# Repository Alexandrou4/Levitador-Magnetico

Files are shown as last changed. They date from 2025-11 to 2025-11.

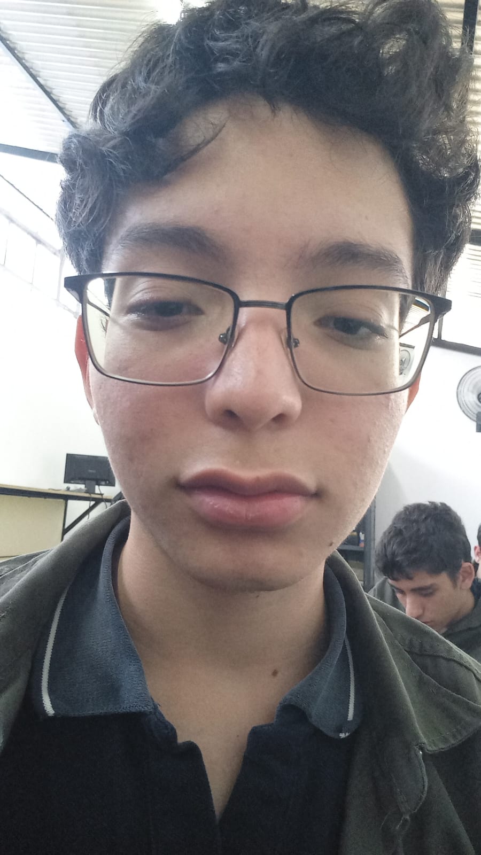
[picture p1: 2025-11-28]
app/Sitio Web/Imagenes/ALEEEEE.jpg

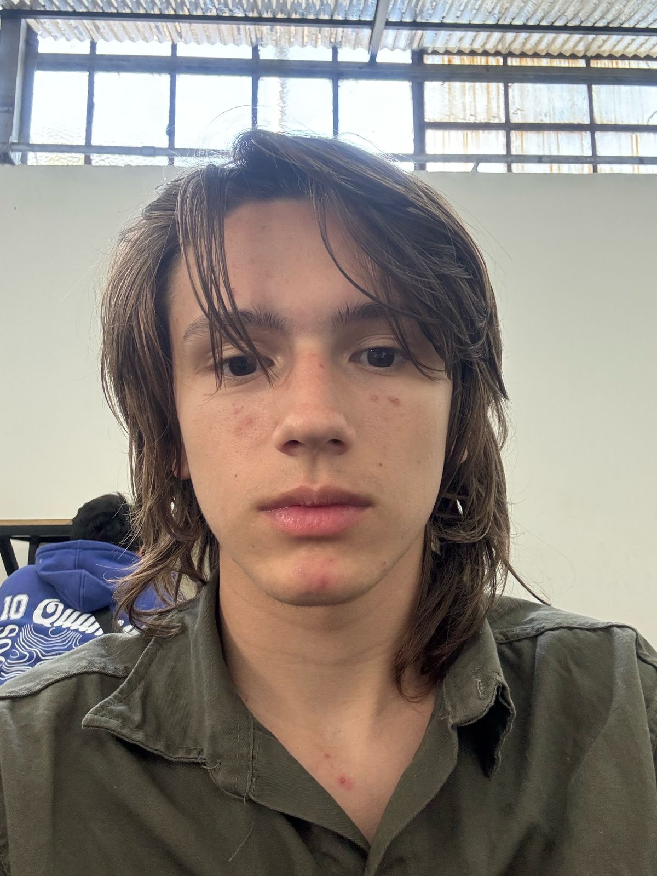
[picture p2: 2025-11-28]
app/Sitio Web/Imagenes/ren.jpg

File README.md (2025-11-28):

<h1 align="center"> **LEVITADOR MAGNÉTICO** </h1>

<h2> Nuestro proyecto, un levitador magnético por repulsión es un dispositivo que utiliza la fuerza de campos magnéticos para suspender un objeto en el aire sin contacto físico. </h2>

<h2> En este utilizamos los principios de electromagnetismo y corrientes eléctricas, PWM (Pulse Width Modulation/Modulación por Ancho de Pulso) y PID (Proporcional-Integral-Derivativo) como un sistema de control para regular constantemente la tensión media inducida en un electroimán en tiempo real y un circuito de potencia que nos permite tener la suficiente alimentación para el bobinado. </h2>

<h2> En este repositorio de Github se encuentran varios directorios como documentación, archivos del firmware, hardware y del sitio web para el facil acceso del lector, con una breve exlicación de los contenidos de cada dirección </h2>

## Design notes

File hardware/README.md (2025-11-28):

<h1 align="center"> HARDWARE </h1>

<h2> Se encuentra una gran parte de los archivos del proyecto en este directorio</h2>

<h2> Se incluyen:</h2>

<h3> -Esquemático</h3>
<h3> -PCB</h3>
<h3> -Gerber</h3>
<h3> -Simbolo RP2040-Zero</h3>
<h3> -Footprint RP2040-Zero</h3>

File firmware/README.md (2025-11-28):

<h1 align="center"> CÓDIGO </h1>

<h2> Código del proyecto insertado en una RP2040-Zero</h2>

<h2> En este código se incluyen los modulos PWM y PID, entra la lectura del SS49E, pasa por una serie de calculos con la funcion PID, y la salida de estos calculos es establecido como el wrap del PWM0 que sale hacia el driver de potencia.</h2>

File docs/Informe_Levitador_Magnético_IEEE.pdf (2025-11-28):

# Informe IEEE Levitador Magnetico ´

1

ro Villegas Gonzalez Alejandro ´
6° 2° AVC
Comision C ´
alejandrovillegasgonzalez@impatrq.com

4

to Gonzalez Camiscia Santiago
6° 2° AVC
Comision C ´
santiagogonzalezcamiscia@impatrq.com

2

do Romero Julian
6° 2° AVC
Comision B ´
julianromero@impatrq.com

5

to Keller Mateo
6° 2° AVC
Comision C ´
mateokeller@impatrq.com

3

ro Erbino Renzo
6° 2° AVC
Comision C ´
renzoerbino@impatrq.com

6

to Gonzalez Paurailly Matias
6° 2° AVC
Comision C ´
matiasgonzalezpaurailly@impatrq.com

Abstract—En este informe se detalla el desarrollo tecnico ´ llevado a cabo, se analiza la metodolog´ıa y conceptos f´ısicos utilizados en el proyecto tales como el PWM y PID, la manera en la que conseguimos la posicion del objeto que levita y como ´
la controlamos mediante el codigo y se demuestra gr ´ | aficamente ´
los procesos que suceden en el circuito tanto electrica como digitalmente.
I. INTRODUCCION´
En este informe estaremos detallando el funcionamiento y desarrollo de nuestro proyecto, un levitador magnetico por ´ repulsion. Este es un dispositivo que utiliza la fuerza de ´ campos magneticos para suspender un objeto en el aire sin ´ contacto f´ısico. En este utilizamos los principios de electromagnetismo y corrientes electricas, PWM (Pulse Width Modu- ´ lation/Modulacion por Ancho de Pulso) y PID (Proporcional- ´ Integral-Derivativo) como un sistema de control para regu-lar constantemente la tension media inducida en un elec- ´ troiman en tiempo real y un circuito de potencia que nos ´ permite tener la suficiente alimentacion para el bobinado. ´
Demostraremos como se realizo y acab ´ | o el proyecto a trav ´ | es´
de los conocimientos que obtuvimos en el proceso y los problemas que tuvimos que superar, los componentes y su
descripcion, la configuracion de estos y el c ´ | odigo que uti- ´
lizamos para lograr que cada etapa del circuito funcione adecuadamente. En la seccion de referencias del documento ´ se incluira un enlace al repositorio de Github del proyecto, ´
donde encontraran informaci ´ | on m ´ | as especifica sobre algunas ´
de las distintas categorias del contenido de este informe.

II. DESCRIPCION´ FUNCIONAL

A. Diagrama en bloques

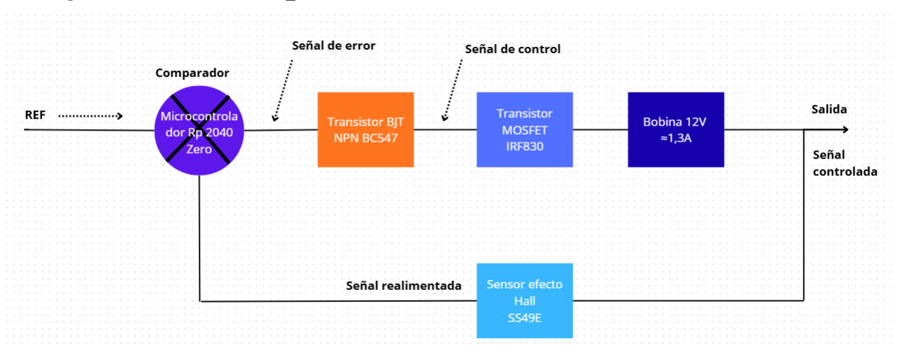
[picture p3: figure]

Fig. 1: Diagrama en bloques del circuito

B. Diagrama de codigo ´

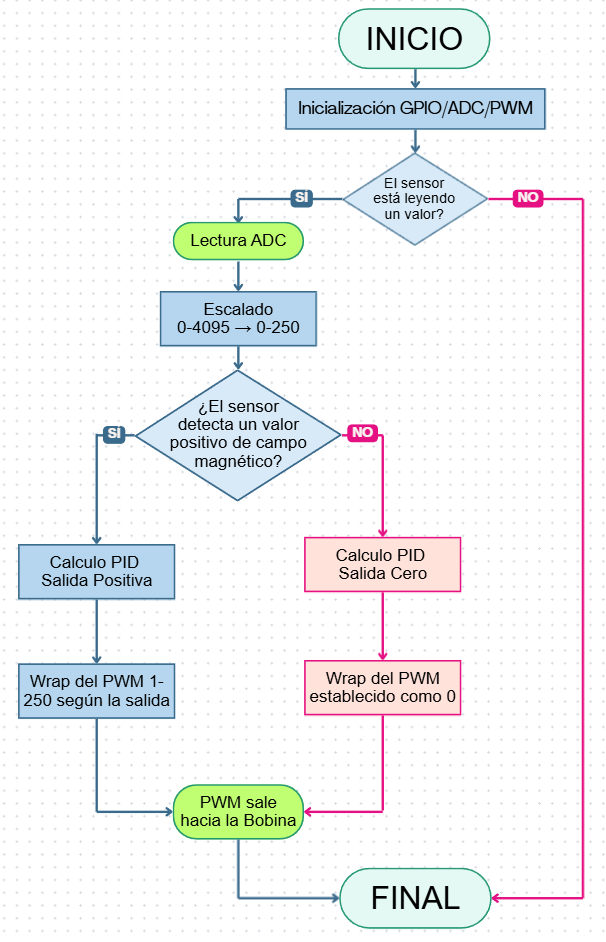
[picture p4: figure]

Fig. 2: Diagrama de codigo del circuito ´

C. Descripcion de circuitos ´
- Microcontrolador RP2040 Zero: Este Microcontrolador es el principal encargado de recibir y procesar los datos provenientes del sensor de efecto Hall. El valor sensado entra a ADC1, donde la computadora lee un valor de 0-4095 y pasa por una serie de calculos con un sistema ´ de control PID con el objetivo de darnos un resultado en permanente oscilacion cercano a un setpoint indicado ´ (126). Este resultado esta escalado en valores de 0-250 y ´ se establece como el wrap de la salida PWM0.
- Diodo HFA15TB60: Evita el dano inmenso que puede ˜ ser generado al MOSFET a causa del alto pico de tension inversa que se genera cuando se apaga la bobina, ´ proporcionando un camino mas seguro para que se disipe ´ esa gran cantidad de energ´ıa.
- Transistor BJT (Driver Inversor): Invierte la senal PWM0 ˜ del microcontrolador, activandose cuando le entra una senal desde PWM0 y apagando el MOSFET, y permi- ˜ tiendo la entrada de la tension de VCC al Gate del ´ MOSFET cuando este no recibe ninguna senal, de tal ˜ modo que a´ısla al microcontrolador de la potencia.
- Transistor MOSFET: Este MOSFET de potencia es el componente que soporta el alto voltaje (VCC) del circuito
y actua como un interruptor electr ´ | onico para la bobina. ´
La senal PWM0 lo controla, y cuando este se prende y se ˜ apaga hace lo mismo con la bobina, conectando su paso a GND.
- Sensor de efecto Hall: Se encarga de sensar el campo electromagnetico generado por la bobina y proporciona ´
un valor de tension anal ´ | ogico que var ´ | ´ıa entre 0V-3.3V
que es le´ıdo por el ADC1 del microcontrolador. Cuando
este no recibe ningun campo magn ´ | etico otorga un valor ´
equivalente a la mitad de la tension de alimentaci ´ | on, en ´
este caso, 1.67V.
- Bobinado: Genera un campo magnetico variable seg ´ | un´
la tension que se le otorga por PWM0 que es le ´ | | ´ıdo por
el sensor de efecto Hall y a su vez permite la repulsion´ con el objeto acoplado a los imanes de neodimio.

III. ALCANCE LOGRADO

Durante el transcurso de este proyecto hemos logrado armar
un electroiman capaz de generar un campo electromagn ´ | etico ´
lo suficientemente potente como para poder repeler una pieza
unida a un iman de neodimio; programar un c ´ | odigo [ ´ | 3] capaz
de generar una salida de PWM(Pulse Width Modulation),
basandose en una se ´ | nal de referencia (Setpoint) y una se ˜ | nal ˜
sensada por el sensor de efecto hall siguiendo un sistema de control PID(Proporcional-Integral-Derivativo); disenar ˜ un circuito capaz de controlar la potencia de la bobina a
traves de la tensi ´ | on media generada por el c ´ | odigo (PWM0), ´
y posteriormente, utilizando la CNC pasarlo a una placa de cobre, perforarla y soldar los componentes; crear una base de madera [4] que pueda sostener de manera vertical a la
bobina y al sensor, contando tambien con un tubo de pl ´ | astico ´
transparente fijado a la parte superior del electroiman el cual ´ impide que la pieza [5] se intente dar vuelta; realizar pruebas, no solo del funcionamiento de la etapa de potencia y del
codigo sino tambi ´ | en de todo al mismo tiempo, verificando si ´
la tension media de la bobina es la indicada por el c ´ | odigo y ´
poder solucionar los problemas que nos encontramos en estas pruebas.

El alcance logrado ha llegado a ser el que nos propusimos como objetivo final tras varios replanteamientos, con lo que logramos el funcionamiento de un levitador electromagnetico ´ pero no sin reducir la propuesta de tres modulos de dos ´ etapas de potencia, un bobinado y un sensor cada uno, con la capacidad de lograr que el objeto levitado permanezca totalmente estatico en el aire. Por otro lado, pudimos realizar ´ una placa f´ısica [6] con el circuito, pero al no suceder lo que deb´ıa esta fue descartada e hicimos nuevamente una
simulacion en un protoboard [ ´ | 7] con otro esquematico [ ´ | 8] y
PCB [9], cuyo funcionamiento cumpl´ıa con el establecido originalmente.

IV. CONCLUSIONES

Con la finalizacion de este proyecto, alcanzamos a aprender ´ la integracion eficaz de los sistemas de control PWM y PID, ´ tambien siendo utilizados los principios de electromagnetismo, ´
calculos matem ´ | aticos complejos tales como las integrales y ´
derivadas que fueron clave para la realizacion del c ´ | odigo e ´
investigamos sobre las propiedades de los cables de cobre, calculo de impedancia por numero de vueltas en una bobina ´
y la maxima corriente capaz de pasar a trav ´ | | es de esta. ´

Logramos entender que el proyecto podr´ıa haber funcionado sin tener que encontrarnos con la gran cantidad de problemas que surgieron a medida que trabajabamos con el proyecto, ´ pero la inmensa obtencion de aprendizaje por la que pasamos ´ no hubiera sido posible sin estos, provocando as´ı que la solucion de los mismos ayude a encaminarnos hacia el ´ correcto funcionamiento del proyecto. A esto se le agrega que el tiempo que dedicamos para el desarrollo del proyecto fue limitado, causando que no hayamos podido realizar la vision´ original que ten´ıamos para este, si no una que se nos ocurrio´ en busqueda de solucionar los errores. Las principales ideas ´ que nos vimos obligados a descartar por la falta de tiempo
fueron la de una pagina web [ ´ | 10] en la que uno controlaba el
angulo de un avi ´ | on, y esto se ve ´ | ´ıa reflejado en la distancia a
la que el objeto a levitar lo hac´ıa, y que hubieran 3 modulos ´ con la configuracion actual, en vez de solo uno, con esto nos ´ referimos a 3 bobinas, sensores y una etapa de potencia en cada una.

En esta etapa final del proyecto concluimos que a pesar de los problemas atravesados el proyecto cumple con su objetivo original integrando los conocimientos de varias areas de taller y aula, dejando en claro las bases sentadas ´ para la mejora y optimizacion del mismo. ´

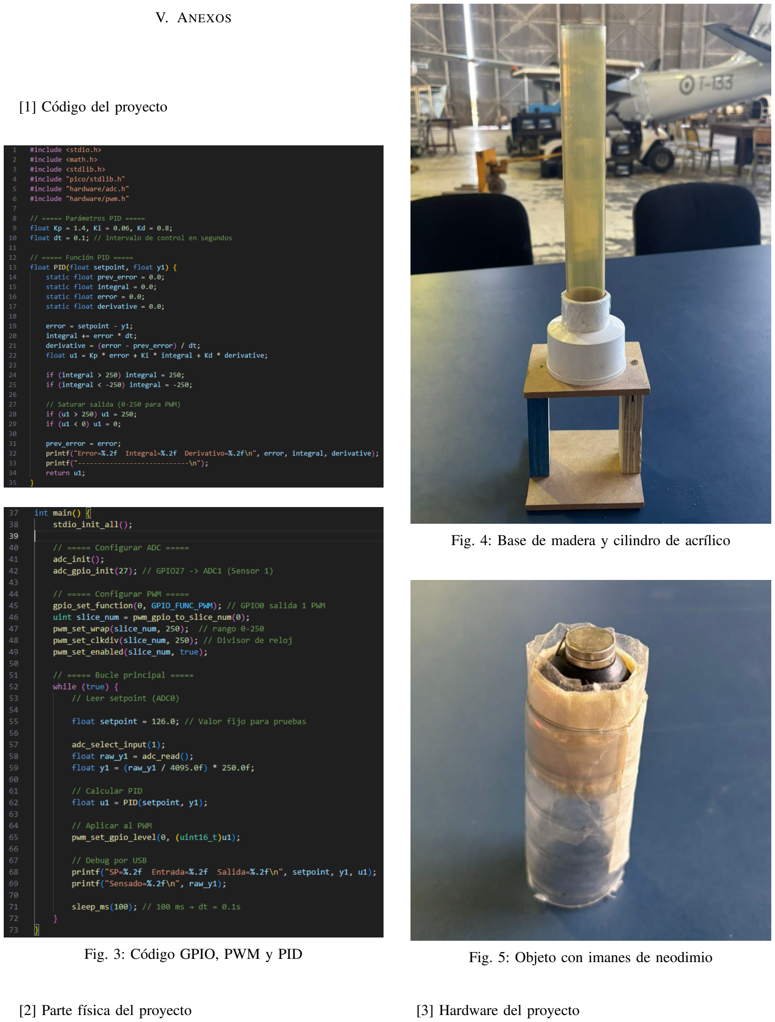
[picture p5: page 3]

V. ANEXOS
[1] Codigo del proyecto ´

Fig. 3: Codigo GPIO, PWM y PID ´

[2] Parte f´ısica del proyecto

Fig. 4: Base de madera y cilindro de acr´ılico

Fig. 5: Objeto con imanes de neodimio

[3] Hardware del proyecto

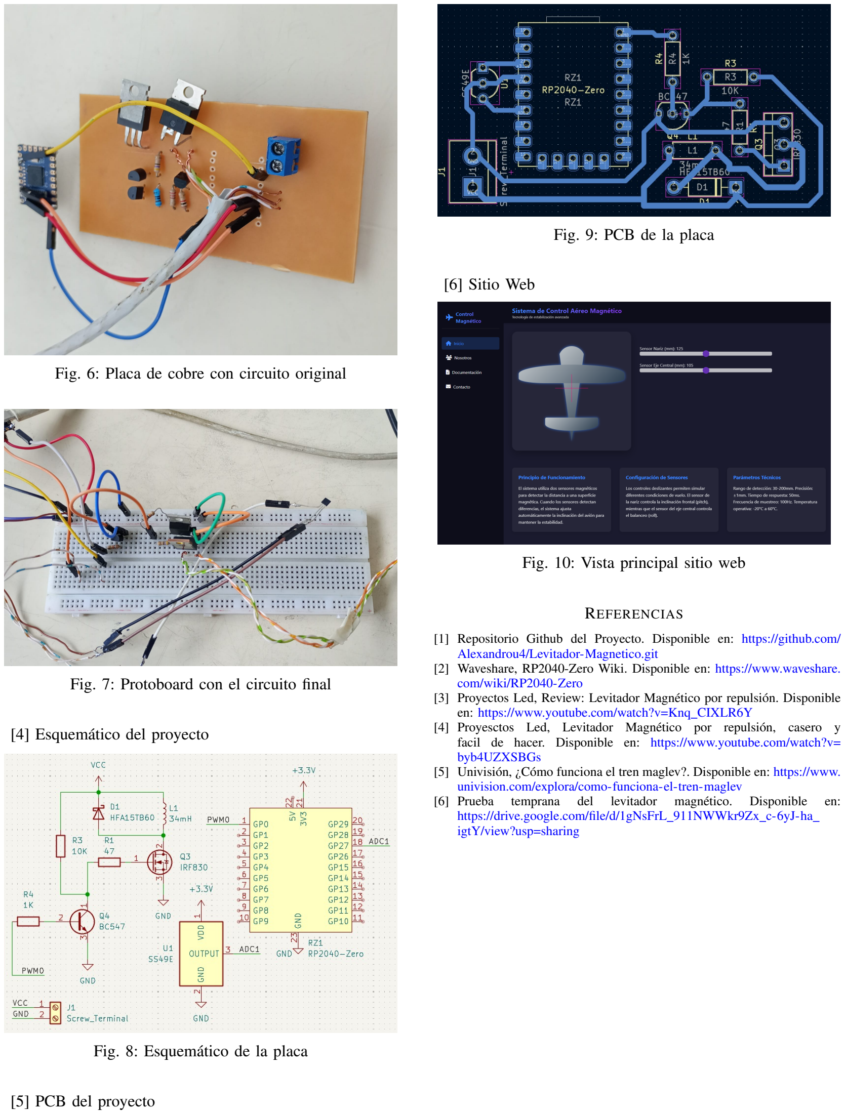
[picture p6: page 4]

Fig. 6: Placa de cobre con circuito original

Fig. 7: Protoboard con el circuito final

[4] Esquematico del proyecto ´

Fig. 8: Esquematico de la placa ´

[5] PCB del proyecto

Fig. 9: PCB de la placa

[6] Sitio Web

Fig. 10: Vista principal sitio web

REFERENCIAS

[1] Repositorio Github del Proyecto. Disponible en: https://github.com/Alexandrou4/Levitador-Magnetico.git (https://github.com/Alexandrou4/Levitador-Magnetico.git)
[2] Waveshare, RP2040-Zero Wiki. Disponible en: https://www.waveshare.com/wiki/RP2040-Zero (https://www.waveshare.com/wiki/RP2040-Zero)
[3] Proyectos Led, Review: Levitador Magnetico por repulsi ´ | on. Disponible ´
en: https://www.youtube.com/watch?v=Knq CIXLR6Y (https://www.youtube.com/watch?v=Knq_CIXLR6Y)
[4] Proyesctos Led, Levitador Magnetico por repulsi ´ | on, casero y ´
facil de hacer. Disponible en: https://www.youtube.com/watch?v=byb4UZXSBGs (https://www.youtube.com/watch?v=byb4UZXSBGs)
[5] Univision, ¿C ´ | omo funciona el tren maglev?. Disponible en: ´ | | | | https://www.
univision.com/explora/como-funciona-el-tren-maglev
[6] Prueba | temprana | del | levitador | magnetico. | Disponible | en: ´
https://drive.google.com/file/d/1gNsFrL 911NWWkr9Zx c-6yJ-ha igtY/view?usp=sharing (https://drive.google.com/file/d/1gNsFrL_911NWWkr9Zx_c-6yJ-ha_igtY/view?usp=sharing)

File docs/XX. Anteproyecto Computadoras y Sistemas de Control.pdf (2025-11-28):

### EEST N°7 - Computadoras y Sistemas de Control - Profesor Carlassara Fabrizio

## ANTEPROYECTO DE “LEVITADOR MAGNÉTICO”

Integrante 1: Julián Romero Integrante 1: julianromero@impatrq.com Integrante 2: Renzo Erbino Integrante 2: renzoerbino@impatrq.com Integrante 3: Alejandro Villegas González Integrante 3: alejandrovillegasgonzalez@impatrq.com Integrante 4: Santiago González Camiscia Integrante 4: santiagogonzalezcamiscia@impatrq.com Integrante 5: Keller Mateo Integrante 5: mateokeller@impatrq.com Integrante 6: Matías González Paurailly Integrante 6: matiasgonzalezpaurailly@impatrq.com

## 1. INTRODUCCIÓN

El proyecto consiste en el diseño y desarrollo de un levitador magnético por repulsión, un dispositivo que utiliza la fuerza de campos magnéticos para suspender un objeto en el aire sin contacto físico. Esto se logra a través del uso de electroimanes, que permiten contrarrestar la fuerza de la gravedad y mantener el objeto estable.
Con este proyecto se pretende utilizar principios del electromagnetismo, especialmente la interacción entre campos magnéticos y corrientes eléctricas. Para lograr una levitación estable, se utilizará un sistema de retroalimentación con sensores de efecto Hall, que junto a un circuito permitirá regular la corriente en el electroimán en tiempo real manteniendo así el objeto estable.

## 2. MARCO DE APLICACIÓN

Una de las áreas actuales de aplicación de los levitadores magnéticos es el transporte, por ejemplo el tren Maglev, un tren bala que se mueve usando el principio de propulsión electromagnética. Definitivamente este es un uso que se podría expandir en el futuro, o en el transporte de objetos frágiles sin hacer contacto con ellos. [1]

## 3. DESCRIPCIÓN TÉCNICA

## 3.1 SOBRE EL HARDWARE

- Microcontrolador: Raspberry Pi Pico o Esp32.
Con el microcontrolador analizaremos la corriente sensada a través de los sensores Hall, y en base a ese valor daremos más potencia a una bobina y menos a las otras dos.
El microcontrolador será quien se encargue de regular la tensión que caerá en las bobinas y las variables monitoreadas serán las mediciones de los sensores hall, las cuales al ser mayores significan una mayor cercanía a los sensores, y al ser menores indican lejanía.
- Bobinas: hechas con alambre de cobre Las bobinas son las que se encargan de mantener el imán en el aire, en este caso, a través de fuerzas de repulsión, las bobinas tendrán un núcleo de ferrita.
- Diodo: DL4005
El diodo estará situado en paralelo a la bobina polarizado en inversa, para evitar que le llegue corriente inducida por la bobina al microcontrolador.
- Driver de potencia: transistor MOSFET IRLZ44N.
Será el encargado de facilitar el control de las bobinas a través del microcontrolador.
- Resistencias varias.

1

### EEST N°7 - Computadoras y Sistemas de Control - Profesor Carlassara Fabrizio

## 3.2 SOBRE EL SOFTWARE

Código realizado en C, se importa el código al microcontrolador. Desde el microcontrolador se envía a diferentes pines para accionar las diferentes herramientas del microcontrolador PWM, PID, sensor y transistor Mosfet.

## 4. DIVISIÓN DE TAREAS

## 4.1 INTEGRANTE 1 (JR)

- Diseño y simulación del circuito
- Investigación de los principios físicos de la levitación magnética

## 4.2 INTEGRANTE 2 (RE)

- Investigación de sensores, componentes y otros elementos a utilizar. Análisis de costo y disponibilidad
- Desarrollo de la página web del proyecto

## 4.3 INTEGRANTE 3 (AVG)

- Investigación de usos actuales, posibles usos futuros y proyectos ya existentes
- Desarrollo de la página web del proyecto

## 4.4 INTEGRANTE 4 (SGC)

- Programación del microcontrolador para la regulación del campo magnético. Implementación de lectura de sensores y lógica de control.

## 4.5 INTEGRANTE 5 (MK)

- Encargado del montaje físico de la estructura del proyecto (base, soporte, electroimanes)

## 4.6 INTEGRANTE 6 (MGP)

- Programación del microcontrolador para la regulación del campo magnético. Implementación de lectura de sensores y lógica de control.

## 5. LISTA DE MATERIALES

- Diodo fr107.
comprado
- Resistencia 220Ω.
comprado
- Transistor MOSFET IRLZ44N. comprado
- Microcontrolador. Raspberry Pi pico w. Comprada
- Sensor de efecto Hall. 5x4000$ars
Lote 5x Sensor Efecto Hall A3144 Switch
-pdiy- | MercadoLibre (https://articulo.mercadolibre.com.ar/MLA-1151531325-lote-5x-sensor-efecto-hall-a3144-switch-pdiy--_JM)
referencia de alambre de cobre de 0,5mm Comprado
Valor total a pagar:4000$ars o 600$ars por persona+cobre esmaltado.

## 5. REFERENCIAS

Agregar cualquier referencia que se haya usado durante la investigación o el informe.

[1] Referencia 1. Cómo funciona el tren Maglev (https://www.univision.com/explora/como-funciona-el-tren-maglev)
[2] Referencia 2. Review: l|evitador magnético por repulsión (https://www.youtube.com/watch?v=Knq_CIXLR6Y)
[3] Referencia 3. Al fin lo pude hacer!!! Levitador magnetico por repulsion. casero y facil de hacer (https://www.youtube.com/watch?v=byb4UZXSBGs)

2

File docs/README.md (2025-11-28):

<h1 align="center"> DOCUMENTACIÓN </h1>

<h2> En este directorio se encuentra toda la documentación realizada sobre el proyecto en el transcurso del año para varios talleres, incluyendo un anteproyecto, un informe estilizado IEEE y uno más con un formato más simple </h2>

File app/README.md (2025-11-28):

<h1 align="center"> SITIO WEB </h1>

<h2>Esta pagina web fue creada con la intención de ser usada como referencia visual para la posición del objeto levitado, el ángulo de este y poder controlarlo manualmente mediante los controles deslizantes con la figura de un avión en el medio que a su vez se mueve con los controles también.</h2>

Sitio Web

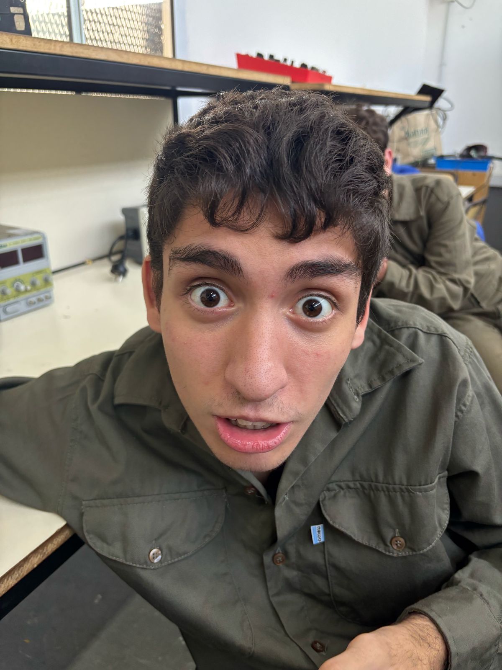
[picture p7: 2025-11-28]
app/Sitio Web/Imagenes/mati.jpg

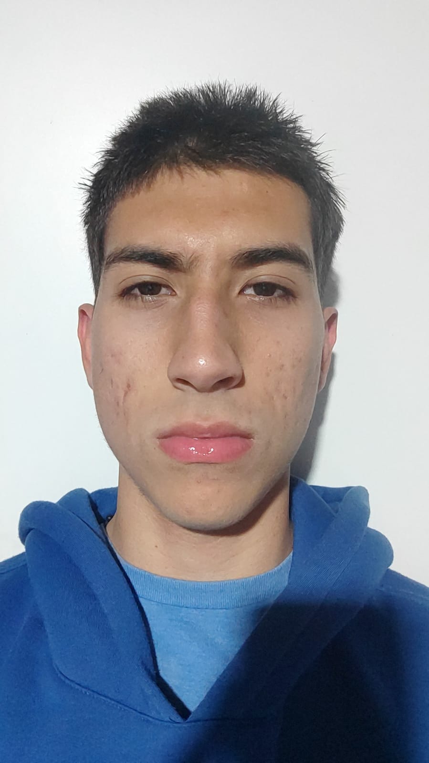
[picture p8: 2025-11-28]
app/Sitio Web/Imagenes/juli.jpg

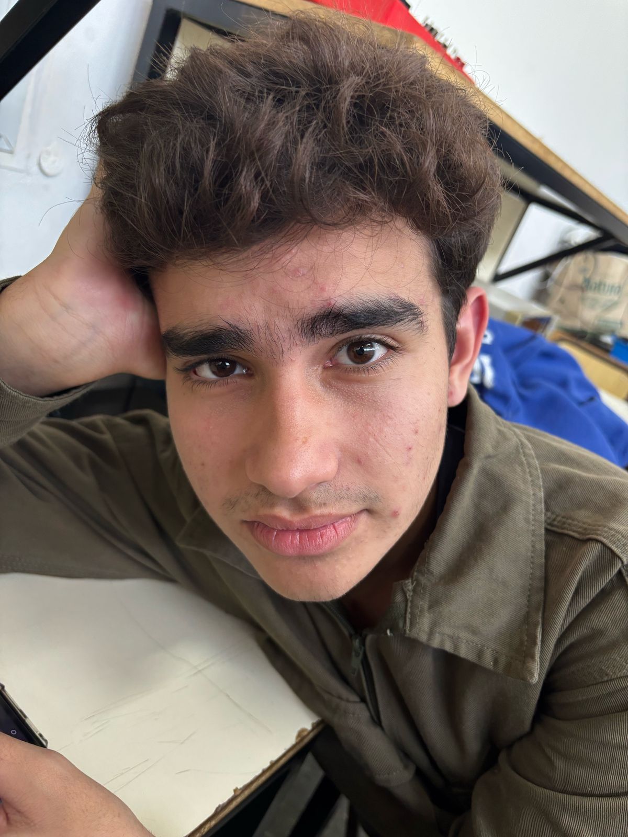
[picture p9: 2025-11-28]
app/Sitio Web/Imagenes/mate.jpg

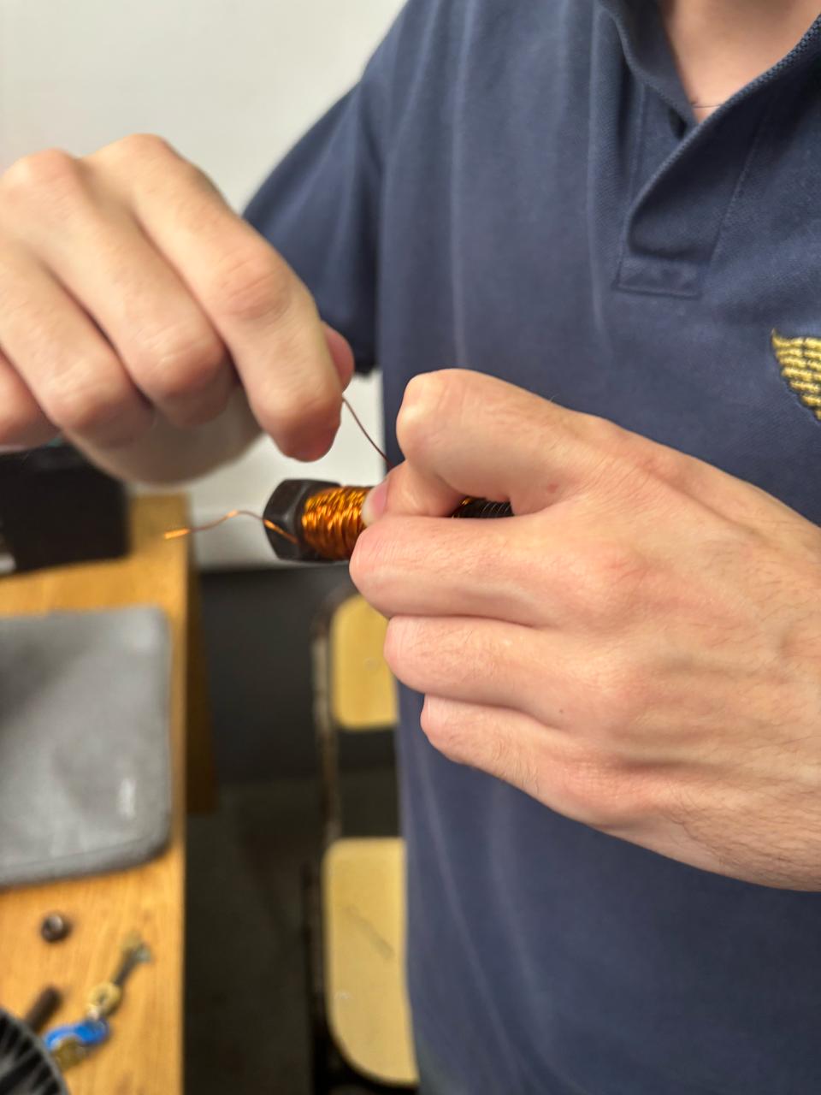
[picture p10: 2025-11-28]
app/Sitio Web/Imagenes/Bobinado.jpg

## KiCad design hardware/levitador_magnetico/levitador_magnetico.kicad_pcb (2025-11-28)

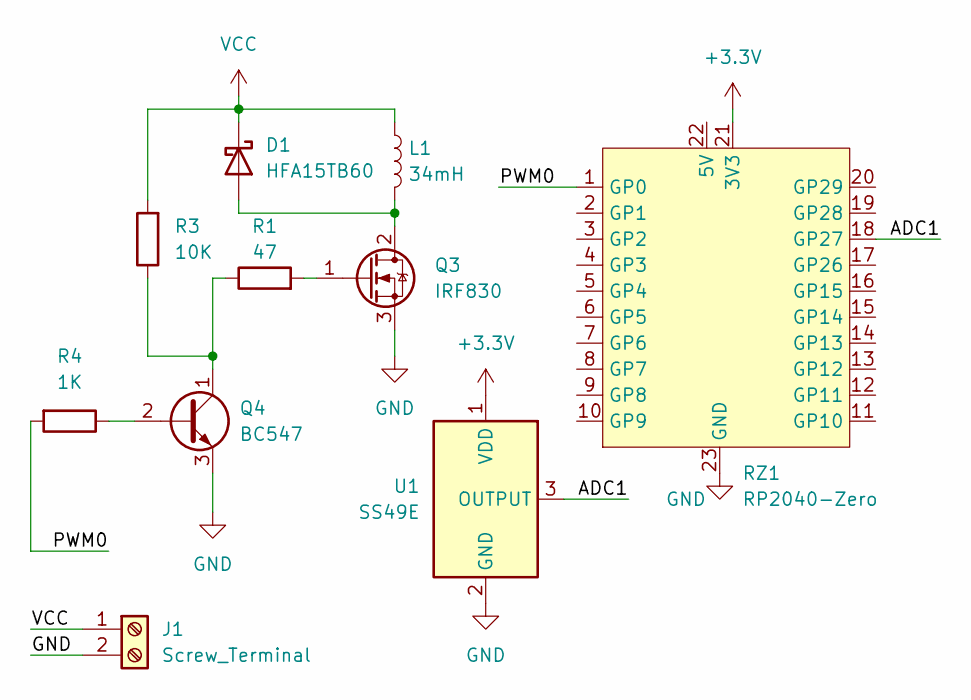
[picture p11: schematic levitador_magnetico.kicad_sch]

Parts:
D1: HFA15TB60; D_DO-41_SOD81_P10.16mm_Horizontal
J1: Screw_Terminal; TerminalBlock_bornier-2_P5.08mm
L1: 34mH; R_Axial_DIN0207_L6.3mm_D2.5mm_P7.62mm_Horizontal
Q3: IRF830; TO-220-3_Vertical
Q4: BC547; TO-92_Inline
R1: 47; L_Axial_L5.3mm_D2.2mm_P7.62mm_Horizontal_Vishay_IM-1
R3: 10K; L_Axial_L5.3mm_D2.2mm_P7.62mm_Horizontal_Vishay_IM-1
R4: 1K; L_Axial_L5.3mm_D2.2mm_P7.62mm_Horizontal_Vishay_IM-1
RZ1: RP2040-Zero
U1: SS49E; TO-92_Inline_Wide

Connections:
+3.3V: RZ1.21 (3V3), U1.1 (VDD)
/ADC1: RZ1.18 (GP27), U1.3 (OUTPUT)
/PWM0: R4.2, RZ1.1 (GP0)
GND: J1.2, Q3.3 (S), Q4.3 (E), RZ1.23 (GND), U1.2 (GND)
unnamed: D1.2 (A), L1.2, Q3.2 (D)
unnamed: Q3.1 (G), R1.2
unnamed: Q4.2 (B), R4.1
unnamed: Q4.1 (C), R1.1, R3.1
VCC: D1.1 (K), J1.1, L1.1, R3.2

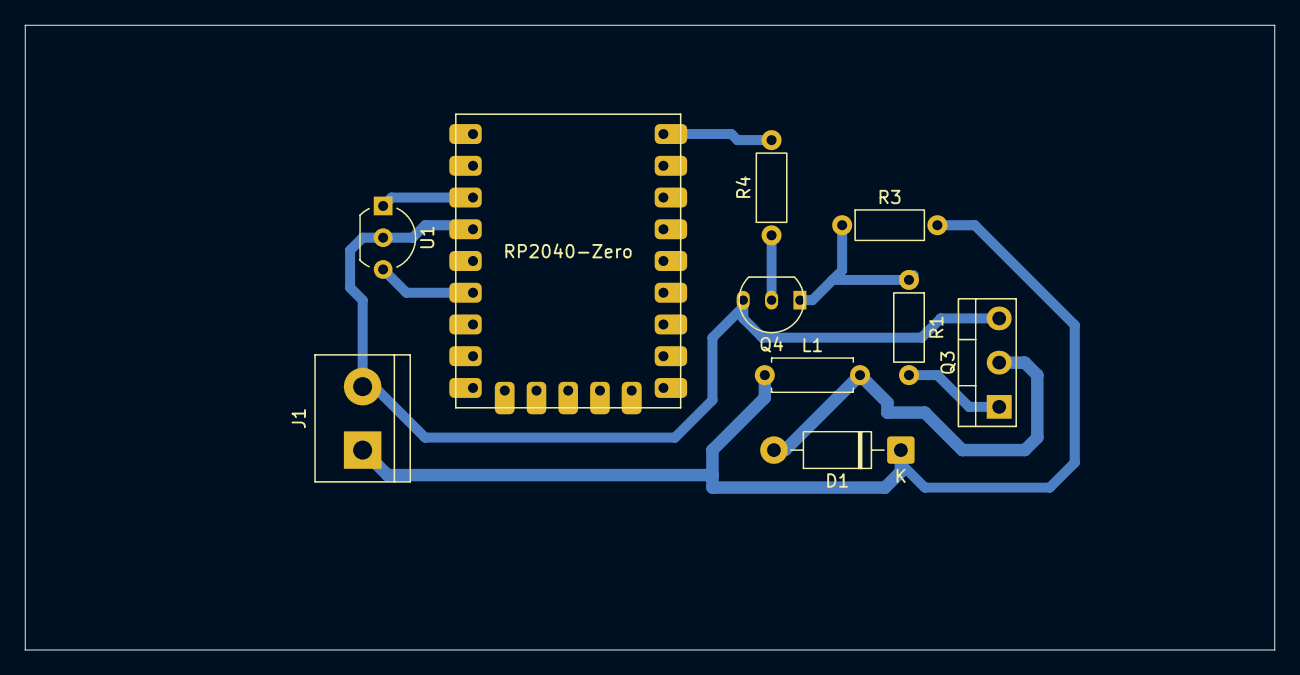
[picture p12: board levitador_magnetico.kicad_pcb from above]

Board: 2 copper layers, 100.0 x 50.0 mm, 10 parts (0 on the bottom side), 9 nets.

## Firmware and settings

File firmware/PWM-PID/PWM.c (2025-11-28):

#include <stdio.h>
#include <math.h>
#include <stdlib.h>
#include "pico/stdlib.h"
#include "hardware/adc.h"
#include "hardware/pwm.h"

// ===== Parámetros PID =====
float Kp = 1.4, Ki = 0.06, Kd = 0.8;
float dt = 0.1; // intervalo de control en segundos

// ===== Función PID =====
float PID(float setpoint, float y1) {
    static float prev_error = 0.0;
    static float integral = 0.0;
    static float error = 0.0;
    static float derivative = 0.0;

    error = setpoint - y1;
    integral += error * dt;
    derivative = (error - prev_error) / dt;
    float u1 = Kp * error + Ki * integral + Kd * derivative;

    if (integral > 250) integral = 250;
    if (integral < -250) integral = -250;

    // Saturar salida (0-250 para PWM)
    if (u1 > 250) u1 = 250;
    if (u1 < 0) u1 = 0;

    prev_error = error;
    printf("Error=%.2f  Integral=%.2f  Derivativo=%.2f\n", error, integral, derivative);
    printf("----------------------------\n");
    return u1;
}

int main() {
    stdio_init_all();

    // ===== Configurar ADC =====
    adc_init();
    adc_gpio_init(27); // GPIO27 -> ADC1 (Sensor 1)

    // ===== Configurar PWM =====
    gpio_set_function(0, GPIO_FUNC_PWM); // GPIO0 salida 1 PWM
    uint slice_num = pwm_gpio_to_slice_num(0);
    pwm_set_wrap(slice_num, 250);  // rango 0-250
    pwm_set_clkdiv(slice_num, 250); // Divisor de reloj
    pwm_set_enabled(slice_num, true);

    // ===== Bucle principal =====
    while (true) {
        // Leer setpoint (ADC0)

        float setpoint = 126.0; // Valor fijo para pruebas

        adc_select_input(1);
        float raw_y1 = adc_read();
        float y1 = (raw_y1 / 4095.0f) * 250.0f;

        // Calcular PID
        float u1 = PID(setpoint, y1);

        // Aplicar al PWM
        pwm_set_gpio_level(0, (uint16_t)u1);

        // Debug por USB
        printf("SP=%.2f  Entrada=%.2f  Salida=%.2f\n", setpoint, y1, u1);
        printf("Sensado=%.2f\n", raw_y1);

        sleep_ms(100); // 100 ms → dt = 0.1s
    }  
}
